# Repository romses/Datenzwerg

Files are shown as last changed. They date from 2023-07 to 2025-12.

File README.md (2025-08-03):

# Datenzwerg

## Development

Install Python 3.11. Then

1. `python -m venv venv`
2. `source venv/bin/activate`
3. `pip install -r requirements.txt`

This will install all dependencies for firmware and documentation development into a virtual environment and activate it. To leave the virtual environment, run `deactivate`.

### Firmware

The Datenzwerg firmware is based on [esphome](https://esphome.io/) which gets installed as dependency when running the above setup command.

> [!NOTE]
>
> The firmware currently requires ESPHOME 2025.7.4, as set in the `requirements.txt`. Other versions might cause errors.

To flash your own Datenzwerg, navigate to the `firmware` directory, then

1. Copy `secrets-template.yaml` to `packages/secrets.yaml` and fill in your WiFi and InfluxDB2 credentials.
2. Run `esphome -s name <gnome> run datenzwerg-{psu|battery|sensortest}.yaml` to compile and flash the firmware for your gnome named `<gnome>`.
   - `psu`: firmware optimized for deployment with a power supply; includes uptime, CO2 sensor and MQTT
   - `battery`: firmware optimized for deployment with a battery; disables uptime, CO2 sensor and MQTT but enables deepsleep
   - `sensortest`: firmware for testing all sensors; enables a webserver to check tracking

### Models

The gnome model files are based on https://www.printables.com/model/260908-garden-gnome by [Sci3D](https://www.printables.com/@Sci3D), released under CC-BY.

In the `models` directory, you will find the following files:

  - **Gnome body**
    - `datenzwerg_40p_1.2mm.blend`: Main design file, edit with [Blender](https://blender.org)
    - `datenzwerg_40p_1.2mm_top.stl`: Upper body, electronics compartment
    - `datenzwerg_40p_1.2mm_bottom.stl`: Lower body, feet, mount point
    - `datenzwerg_40p_1.2mm_bottom_poe.stl`: Lower body, feet, mount point, PoE versionA
    - `datenzwerg_logo.svg`: Logo in SVG format
  - **Gnome mounting**
    - `ground-plate-bottom.FCStd`: Ground plate design file, edit with [FreeCAD](https://freecad.org)
    - `ground-plate-bottom.stl`: Ground plate bottom part
  - **Gnome transport L-Boxx**
    - `l-boxx-136-inlay.FCStd`: L-Boxx Inlay design file, edit with [FreeCAD](https://freecad.org)
    - `label-l-boxx.svg`: Label for the L-Boxx
  - **Various labels**
    - `label-2024.svg`: Gnome label for 37c3

### Documentation

The documentation is built with [MkDocs](https://www.mkdocs.org/) which gets installed as dependency when running the above setup command. The documentation source files are located in the `docs` directory, the configuration in `mkdocs.yml` in the project root.

To run a live-reload server, run

```
mkdocs serve
```

To build the documentation, run

```
mkdocs build
```

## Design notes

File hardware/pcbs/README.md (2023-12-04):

# Gerber files

- v1.0: CCCamp2023 edition
- v1.1: 37c3 edition

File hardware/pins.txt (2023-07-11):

# Wemos D1 Mini
# -------------

TX: X           RST: D0
RX: X           A0 : X
D1: DCL         D0 : RST
D2: SDA         D5 : X
D3: X           D6 : Sensor_PWR (UV_PWR, BME_PWR, SND_PWR)
D4: X           D7 : X
G               D8 : X
5V              3V3

# ADS1115
# -------

VDD: 5V (WEMOS_5V, PWR_5V)
GND
SCL: WEMOS_D1
SDA: WEMOS_D2
X
X
A0 : UV_Out
A1 : Batt_Out
A2 : SND_Out
A3 : X

# UV
# ---

SIG: ADS1115_A0
GND
3V3: Wemos_D6

# BME280
# ------

SDA: WEMOS_D1
SCL: WEMOS_D2
GND
3V3: Wemos_D6

# SND
# ---

SIG: ADS1115_A2
GND
3V3: Wemos_D6

# PWR
# ---

SIG: ADS1115_A1
GND
5V : WEMOS_5V, ADS1115_VDD

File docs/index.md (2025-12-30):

---
description: "The Datenzwerg is a garden gnome with a mission: To collect environmental data and make it publicly available."
---

# The Datenzwerg

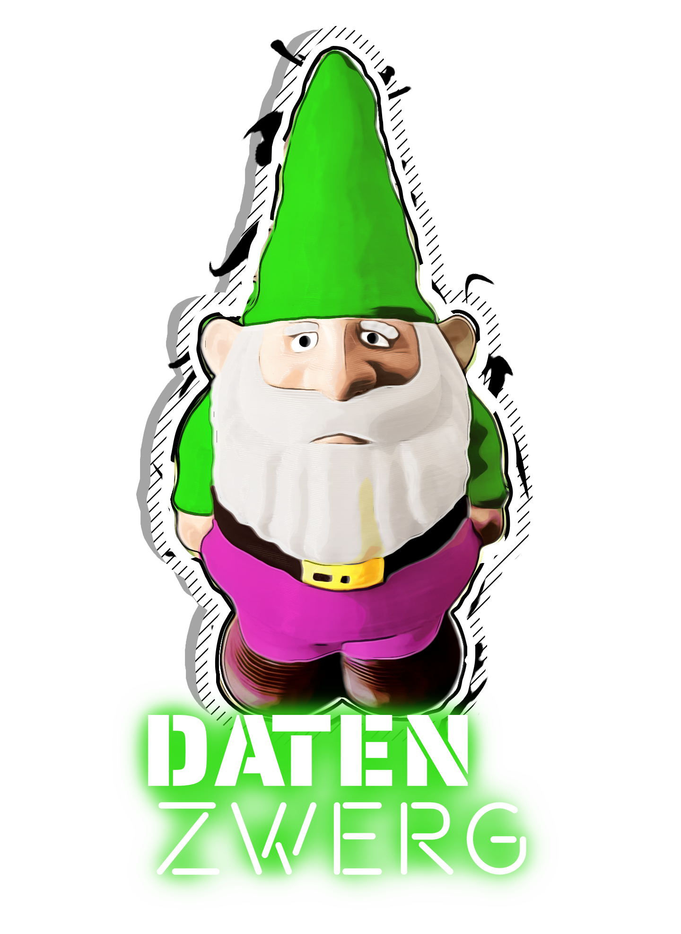
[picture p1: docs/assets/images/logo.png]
Datenzwerg logo


**Next planned deployment**: tbd

<!--
!!! tip "Datenzwerg @ 39C3"

    You are at 39C3 and came across one of the Datenzwerge? Awesome! Here's some quick links for you:

    - [What is the Datenzwerg?](#what-is-the-datenzwerg)
    - [FAQ](#faq)
    - [Fancy dashboards at grafana.datagnome.de](https://grafana.datagnome.de)

    And if you are wondering where each Datenzwerg is located, here's a quick overview. Clicking on the name will take you to the respective dashboard:

    | Datenzwerg | Location |
    | ---------- | -------- |
    | [Bashful](https://grafana.datagnome.de/d/f17a6449-84ed-4733-b982-21c0d480c42a/overview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) | Chaosmentoren |
    | [Dopey](https://grafana.datagnome.de/d/f17a6449-84ed-4733-b982-21c0d480c42a/overview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) | Food Hacking Area |
    | [Grumpy](https://grafana.datagnome.de/d/f17a6449-84ed-4733-b982-21c0d480c42a/overview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) | Memleak Bar |
    | [Happy](https://grafana.datagnome.de/d/f17a6449-84ed-4733-b982-21c0d480c42a/overview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) | C3cat Assembly |
    | [Hefty](https://grafana.datagnome.de/d/f17a6449-84ed-4733-b982-21c0d480c42a/overview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) | Chaos West |
    | [Kinky](https://grafana.datagnome.de/d/f17a6449-84ed-4733-b982-21c0d480c42a/overview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) | House of Tea |
    | [Moopsy](https://grafana.datagnome.de/d/f17a6449-84ed-4733-b982-21c0d480c42a/overview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) | Chaospost |
    | [Nerdy](https://grafana.datagnome.de/d/f17a6449-84ed-4733-b982-21c0d480c42a/overview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)  | Kidspace |
    | [Sleepy](https://grafana.datagnome.de/d/f17a6449-84ed-4733-b982-21c0d480c42a/overview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) | Saal 4 Chillout |
    | [Sneezy](https://grafana.datagnome.de/d/f17a6449-84ed-4733-b982-21c0d480c42a/overview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) | Hardware Hacking |
-->

## What is the Datenzwerg?

The Datenzwerg is a garden gnome with a mission: To collect environmental data and make it publicly available. 

It was originally developed for the [Chaos Communication Camp 2023](https://events.ccc.de/camp/2023/infos/) where we ([@romses](https://chaos.social/@romses) and [@foosel](https://chaos.social/@foosel)) deployed a small army of 10 Datenzwerge across the camp grounds: Happy, Doc, Grumpy, Dopey, Bashful, Sleepy, Sneezy, Nerdy, Kinky and Hefty[^1]. Since then, Doc has gotten a new home at the CERT and the official Datenzwerg family now consists of Bashful, Dopey, Grumpy, Happy, Hefty, Kinky, Moopsy, Nerdy, Sleepy and Sneezy.

The Datenzwerge also made a reappearance at the [37c3](https://events.ccc.de/congress/2023/infos/index.html), the [GPN22](https://entropia.de/GPN22), the [MRMCD 2024](https://2024.mrmcd.net/de/) and [38c3](https://events.ccc.de/congress/2024/infos/index.html). They are scheduled to make an appearance at [WHY2025](https://why2025.org/).

The Datenzwerg consists of a 3D printed gnome body, a custom PCB with an ESP8266 D1 Mini microcontroller board, a BME280, SCD41, UV and sound sensor and an optional 18650 battery. It's powered by [ESPHome](https://esphome.io/) and sends its data to an [InfluxDB](https://www.influxdata.com/) instance. The firmware currently logs temperature, relative and absolute humidity, air pressure, dew point, UV index, CO2 and sound pressure.

## A short history of the Datenzwerg

2023-06-11
: The idea of the Datenzwerg is born at the final day of  [GPN21](https://entropia.de/GPN21), just before a joint bar shift by [@romses](https://chaos.social/@romses) and [@foosel](https://chaos.social/@foosel). 
  Slow parts of the shift as well as the drive back to the Rhein-Main-Area are spent discussing the idea. Romses registers a domain name.

2023-06-30
: romses and foosel meet up for a joint tinkering session. The first two mainboards are built. The Datenzwerg is alive!

2023-07-08
: Another joint tinkering session takes place. Another 8 mainboards are built. The Datenzwerg army is growing!

2023-07-19
: After finalizing the model and followed by 60+ hours of collective print time, all 10 Datenzwerg bodies are printed.

2023-07-23
: The basic infrastructure goes live. Sensors start to report to the official servers at [datagnome.de](https://datagnome.de).

: All Datenzwerg bodies are prepared for getting their electronics installed: Magnets are glued in, the UV transmissive discs are installed and any holes filled with milliput.

2023-07-24
: The firmware reaches a first feature complete state.

2023-07-28
: All Datenzwerge are now in their bodies and are happily sending data.

2023-08-04
: The website reaches a first complete state in both German and English.

2023-08-09
: The sensor data is publicly available via InfluxDB and MQTT.

: The firmware sees final adjustments in preparation for the Camp.

2023-08-11
: The Datenzwerge are offline again, temporarily. Next stop: CCCamp!

2023-08-15 - 2023-08-19
: Datenzwerg deployment at [CCCamp23](https://events.ccc.de/camp/2023/infos/).

2023-08-19
: (Almost) all Datenzwerge have left the camp and are traveling back to the Rhein-Main-Area. Thanks everyone for the big interest!

2023-08-22
: The Datenzwerge are back home and are being prepared for future deployments. The CCCamp data export is [available in the repository](https://github.com/romses/Datenzwerg/tree/main/camp23_data).

2023-08-28
: The infrastructure has been shut down for now and only the page here and of course the source code remains. The Datenzwerge are taking a well deserved rest.

2023-10-31
: Work has started on the 37c3 edition of the Datenzwerg. The plan is to add TVOC monitoring to the sensor suite. A new PCB has been designed, ordered, arrived, and ten new mainboards have been soldered.

2023-12-08
: An alternative version of the bottom part of the Datenzwerg is finished that allows leading through a cable. Ten new bottoms have been printed and magnetised to allow for USB or POE powering at 37c3. This completes the hardware side of the 37c3 preparations.

2023-12-11
: The server infrastructure is back up an running and the first Datenzwerge are reporting data again.

2023-12-26 - 2023-12-30
: The Datenzwerge are deployed at 37c3.

2024-05-30 - 2024-06-02
: Five Datenzwerge are deployed at GPN22.

2024-10-03 - 2024-10-06
: Eight Datenzwerge are deployed at MRMCD2024.

2024-12-27 - 2024-12-30
: The Datenzwerge are deployed at 38c3.

2025-08-08 - 2025-08-11
: The Datenzwerge are deployed at WHY2025.

## FAQ

### What kind of data does the Datenzwerg collect?

The Datenzwerg contains sensors to collect the following data:

- Temperature
- Relative humidity
- Air pressure
- CO2
- UV sensor voltage
- Microphone voltage
- Battery voltage
- WiFi signal strength

We calculate dew point and absolute humidity from the temperature and relative humidity values, UV index from the UV sensor's voltage and sound pressure (noise level) from the microphone voltage. The calculations are done in firmware.

### Do you record audio?

No. While there is a microphone inside each Datenzwerg hooked up to the ESP's ADC, we only use it to sample 1s of audio every 5s, from which we calculate the peak-to-peak voltage and from that the sound pressure on the Datenzwerg itself. The sample rate is way too low and irregular to record any meaningful audio, and the noise on the line vs the 10-bit ADC would make for a bad experience as well if that was our intention. We are not interested in audio, we are interested in noise levels.

### What's the battery life?

In our tests, a Datenzwerg without CO2 sensor seems to last between three to four days on a single charge of our 18650 LiPos that range from 1600mAh to 2800 mAh. This obviously depends on the cell capacity but also temperature and other environmental factors.

With the CO2 sensor included powering via a single 18650 LiPo is sadly not working out.

### Why are the measured temperatures that high during the day?

We need to put the gnomes into direct sunlight in order to be able to measure UV index. Additionally, the ESP and now also the TVOC sensor are producing heat themselves. We tried to get enough airflow inside the gnome body, but sadly the material itself radiates off heat a lot. As such, the temperature readings are distorted, especially under direct sun light.

### Where can I find the data?

Each Datenzwerg sends its data to a central self-hosted InfluxDB instance. The data is then visualized using Grafana. 

Some of those visualisations as well as credentials for accessing the raw data and links to data exports from past events can be found [here](./sensors/).

### Where can I find the source?

Everything can be found in this GitHub repository: [romses/Datenzwerg](https://github.com/romses/Datenzwerg).

## Media echo

- The datagnomes were the opener at the #cccamp23 review [media.ccc.de](https://media.ccc.de/v/camp2023-57105-cccamp23_review).
- romses and foosel were guests at the [Datenleben Podcast](https://www.datenleben.de/index.php/2023/10/14/dl043-perspektiven-auf-data-science/) and talked about the Datenzwerge (German).
- The Datenzwerg project was also a topic on [C-RadaR](https://www.c-radar.de/2024/06/c-radar-juni-2024-datenzwerge-clubsareculture-verstehbahnhof-emf-camp/)

## Credits & Thanks

The Datenzwerg was created by [@romses](https://chaos.social/@romses) and [@foosel](https://chaos.social/@foosel).

The Datenzwerg logo was created by D.B.

The Datenzwerg model files are based on [this "Garden Gnome" model](https://www.printables.com/model/260908-garden-gnome) by [Sci3D](https://www.printables.com/@Sci3D), released under CC-BY. Our remix can be found [here](https://www.printables.com/model/534875-datenzwerg-enclosure) and of course also [in the GitHub repository](https://github.com/romses/Datenzwerg/tree/main/models).

The SCD41 sensors were sponsored by [@dx@mastodon.social](https://chaos.social/@dx@mastodon.social).

[^1]: Yes, the last three are not canon, and one of them even is a smurf - so what, chaos ftw!

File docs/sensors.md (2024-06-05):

---
description: "A look at the current Datenzwerg sensor data."
---

# Current Datenzwerg data

<!--
There is currently no current Datenzwerg data. Check again when they are back at an event.
-->

## Environmental data

{% for env in grafana.environment %}
=== "{{ env.name }}"
    <iframe src="{{ grafana.base_url }}{{ env.panel }}" class="grafana-iframe"></iframe>
{% endfor %}

## Internal data

{% for env in grafana.internal %}
=== "{{ env.name }}"
    <iframe src="{{ grafana.base_url }}{{ env.panel }}" class="grafana-iframe"></iframe>
{% endfor %}

The full set of grafana dashboards are available at <a href="https://grafana.datagnome.de">grafana.datagnome.de</a>

## Raw data

If you are interested in the raw data, connect to our InfluxDB or MQTT (read-only):

  - InfluxDB:
    - Host: `influxdb.datagnome.de`
    - Port: 8086
    - Organization: `datagnome`
    - Bucket: `datagnome`
    - Auth token: `5amv72PFZxPmnbUISjntEVxtElDYMhkeofg9Deo1ykO6Zy2XIba_iWPcyxyAp_R0dHsvHm5moE4YBCwxGIEriw==`
  - MQTT:
    - Host: `mqtt.datagnome.de`
    - Port: 1883
    - User: `readonly`
    - Password: `readonly`

## Exports of past events

You can find the data export of CCCamp23 [on the repo](https://github.com/romses/Datenzwerg/tree/main/exports/cccamp2023).

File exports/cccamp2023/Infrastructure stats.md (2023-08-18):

Batteriewechsel:
  - Bashful: 2
  - Doc: 2
  - Dopey: 1
  - Grumpy: 1
  - Happy: 1
  - Hefty: 2
  - Kinky: 2
  - Nerdy: 1
  - Sleepy: 1
  - Sneezy: 1
  ---------------
  - total: 14

Stromverbrauch:
  - Bashful: 3 Ah
  - Doc: 3Ah
  - Dopey: 1,5Ah
  - Grumpy: 1,5Ah
  - Happy: 1,5Ah
  - Hefty: 3Ah
  - Kinky: 3Ah
  - Nerdy: 1,5Ah
  - Sleepy: 1,5Ah
  - Sneezy: 1,5Ah
  ----------------
  - total: 21Ah		-> 77 Wattstunden
  
Signal losses:
  - Bashful: 13
  - Doc: 
  - Dopey: 6
  - Grumpy: 5
  - Happy: 
  - Hefty: 3
  - Kinky: 8
  - Nerdy: 3
  - Sleepy: 2
  - Sneezy: 7
  ---------------
  - Most realiable dwarf: Doc/Happy (0)
  - Most lazy dwarf: Bashful (13)
  
Top values:
  - Temperature Max: 44°C (Hefty 2023-08-16 13:40)
  - Temperature Min: 12,8°C (Doc 2023-08-14 6:20)

  - Pressure Max: 1019 mbar
  - Pressure Min: 998 mbar
  
  - Humid Max: 100% (Sleepy 2023-08-16 3:40)
  - Humid Min: 23,9% (Dopey 2023-08-16 16:20)
  
  - UV Max: 9 (Doc 2023-08-16 13:20)

  - SND Max: 94dB (Kinky 2023-08-16 8:00)
  
  - Wifi Max: -69dB (Happy)
  - Wifi Min: -82dB (Sleepy)

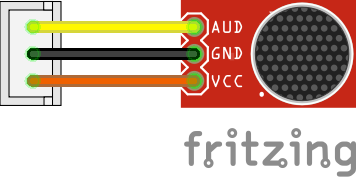
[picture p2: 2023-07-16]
docs/assets/images/Sound-module-fritzing.png

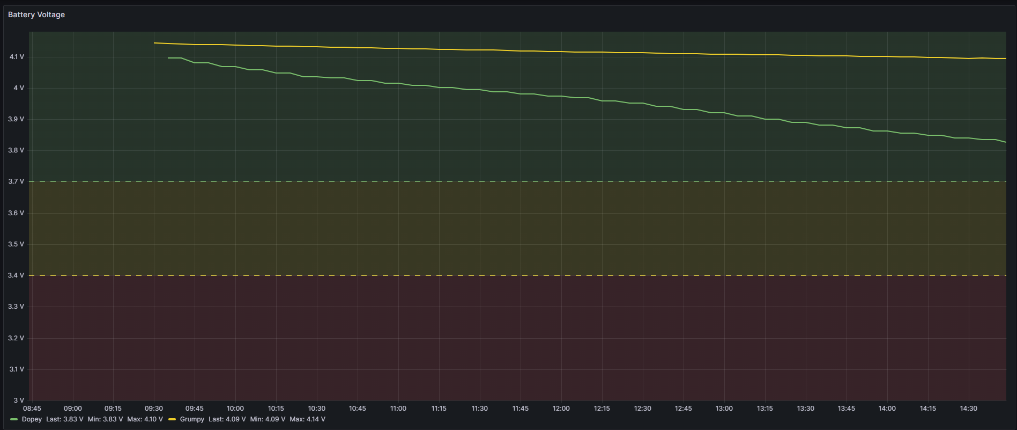
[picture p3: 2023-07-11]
images/Deep-Sleep.png

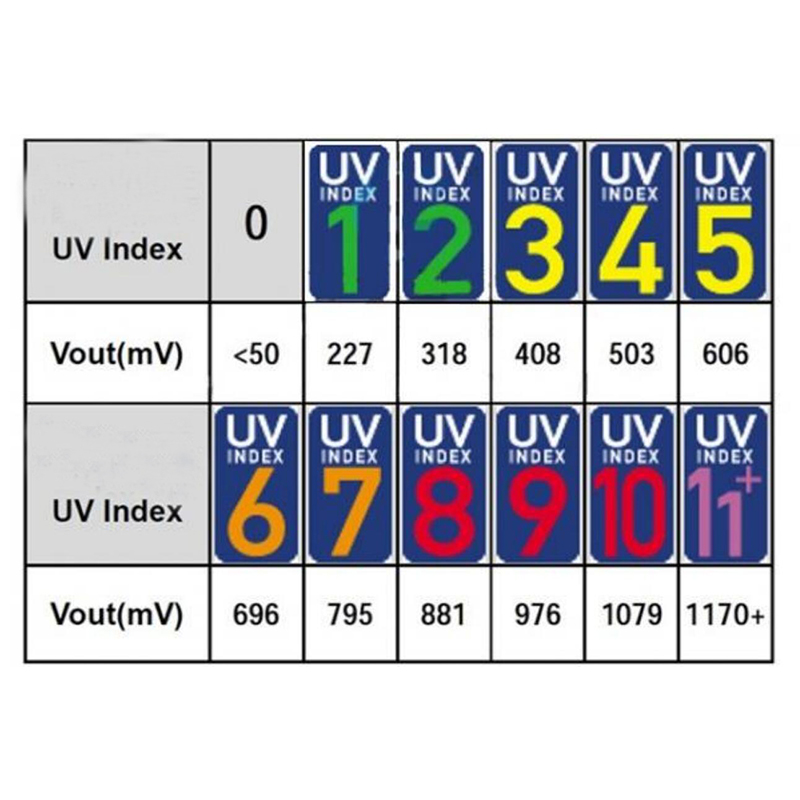
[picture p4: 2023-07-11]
images/UV-Index-table.jpg

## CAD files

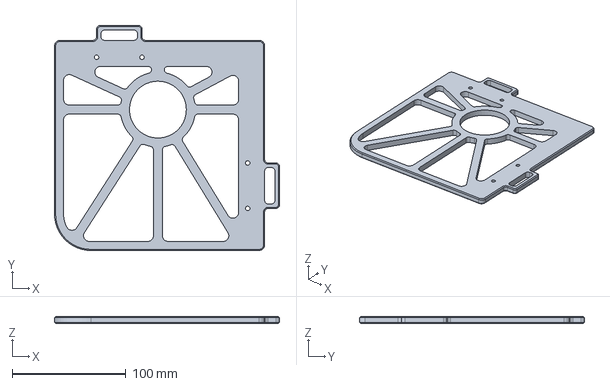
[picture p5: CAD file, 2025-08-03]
models/ground-plate-bottom.FCStd
198.0 x 198.0 x 6.00 mm

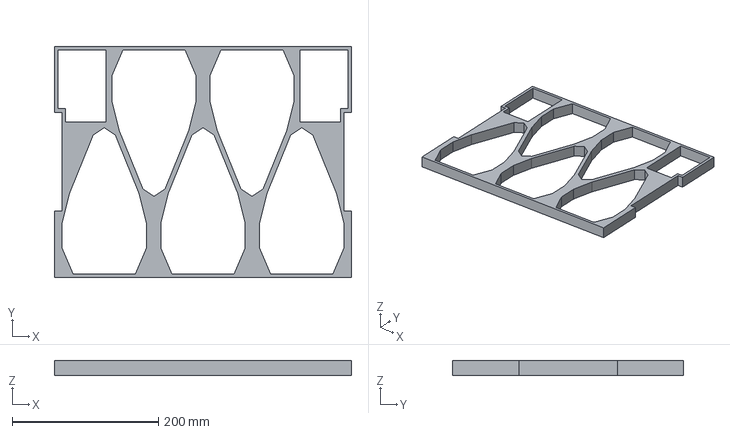
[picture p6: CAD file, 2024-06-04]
models/l-boxx-136-inlay.FCStd
406.0 x 316.0 x 20.0 mm

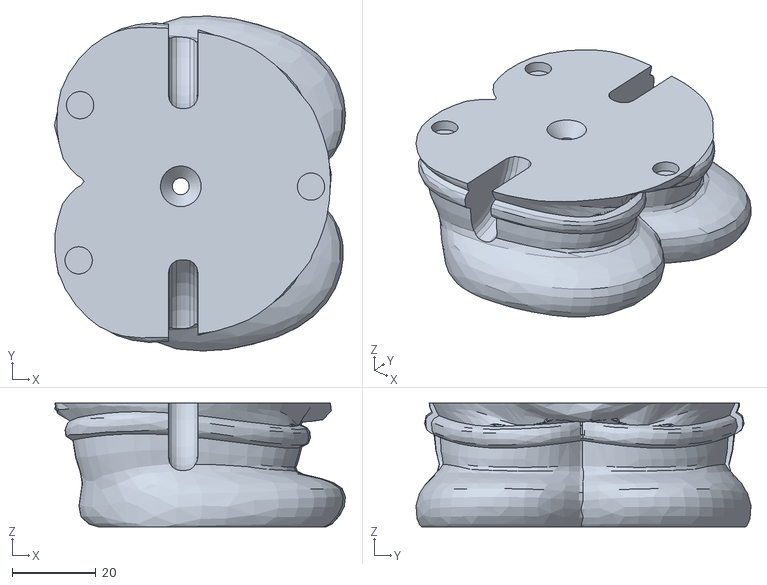
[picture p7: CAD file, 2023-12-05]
models/datenzwerg_40p_1.2mm_bottom_poe.stl
69.3 x 79.8 x 29.4

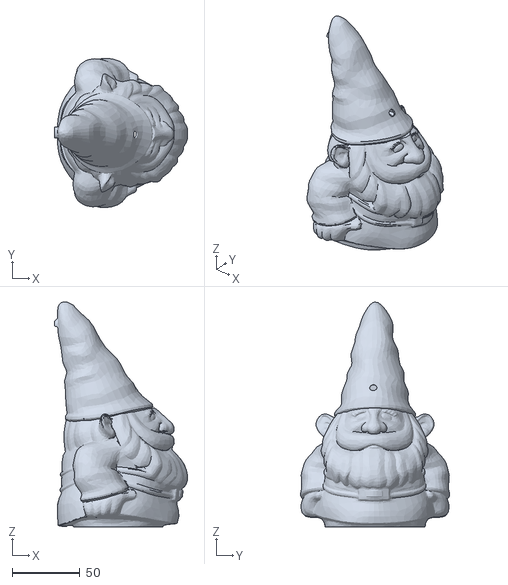
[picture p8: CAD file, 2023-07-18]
models/datenzwerg_40p_1.2mm_top.stl
98.4 x 110.3 x 166.2

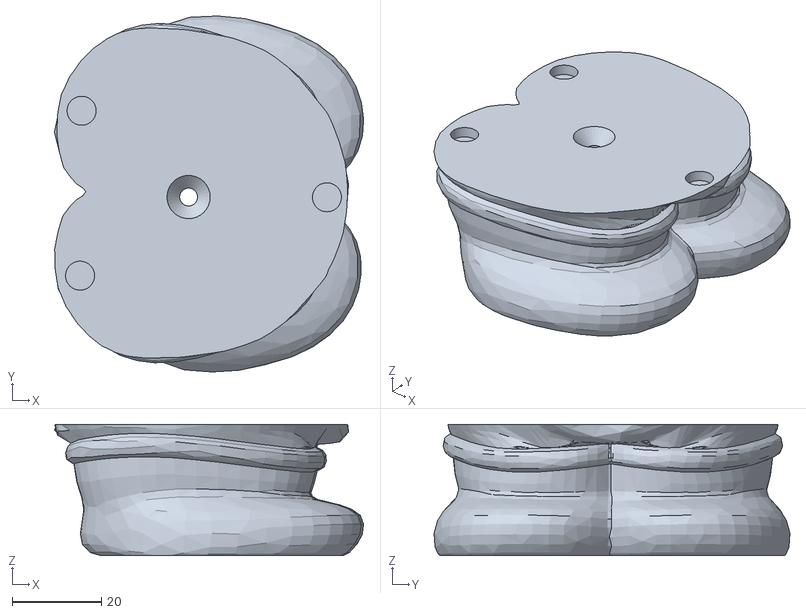
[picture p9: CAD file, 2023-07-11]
models/datenzwerg_40p_1.2mm_bottom.stl
69.3 x 79.8 x 29.4

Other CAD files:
models/ground-plate-bottom.stl

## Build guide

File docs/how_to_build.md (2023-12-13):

---
description: You want to build your own Datenzwerg? Here's a build guide!
---

# How to build a Datenzwerg

!!! warning
    
    The Datenzwerg was initially developed for the [CCCamp23](https://events.ccc.de/camp/2023/infos/) and later adapted for [37c3](https://events.ccc.de/congress/2023/infos/index.html). Hardware, firmware and models were chosen and designed for a specific purpose and a specific deployment duration and might not be suitable for other use cases. The Datenzwerg is provided as-is without any warranty, and also for now without any plans to improve or fix it or any other support. If you want to build your own Datenzwerg, you are mostly on your own.

## Prerequisites

Building a Datenzwerg requires some soldering and 3D printing skills.

The firmware provided with the Datenzwerg requires you to provide it with credentials for an existing WiFi network (SSID and password) and also access to an [InfluxDB2](https://influxdb.com) instance (host, port, organization id, bucket name and write-enabled access token). You will need to provide these credentials in a file called `secrets.yaml` in the `firmware` directory. A template for this file is provided in `firmware/secrets-template.yaml`.

## Parts

### Electronics

To build your own Datenzwerg, you will need the following parts:

| Count | Item | Function | Link |
| ----- | ---- | --- | ---- |
| 1 | Wemos D1 Mini | MCU | [AliExpress](https://aliexpress.com/item/1005004967205772.html) |
| 1 | BME280 | Environment Sensor | [AliExpress](https://aliexpress.com/item/1005003676342598.html) |
| 1 | SGP30 | TVOC/eCO2 Sensor | [AliExpress](https://aliexpress.com/item/1005004680000599.html) |
| 1 | VEML6075 | UV Sensor | [AliExpress](https://aliexpress.com/item/1005004653958045.html) |
| 1 | ADS1115 | 4 Port ADC | [AliExpress](https://aliexpress.com/item/32817162654.html) |
| 1 | GY-MAX4466 | Sound sensor | [Amazon](https://www.amazon.de/dp/B07YDG3VZF) |
| 3 | male 3-pin JST connectors + cables | Sensor & power connectors | [Amazon](https://www.amazon.de/gp/product/B08ZJ6JGB5) |
| 2 | male 4-pin JST connectors + cables | I2C connector | [Amazon](https://www.amazon.de/gp/product/B09LCRCTQG) |
| 2 | male 8-pin headers, male and female | ESP8266 connector | [Amazon](https://www.amazon.de/dp/B07DBY753C/) |
| 1 | male 10-pin header, male and female | ADS1115 connector | [Amazon](https://www.amazon.de/dp/B07DBY753C/) |

Additionally you'll need a soldering iron, solder, some wires and shrink tubing.

!!! warning

    We use BM**E** sensors. They are often mixed up with the BM**P** sensors, which lack the humidity sensor.
    You can identify your module with the help of a picture on this (german) [page](https://homematic-forum.de/forum/viewtopic.php?t=68558).

!!! warning

    If you want to battery power your Datenzwerg, do not use the SGP30 sensor. It requires constant power to work properly and will not work with deep sleep. Leave it unpopulated and adjust the firmware config as described below.

!!! note

    We recommend using all parts from the BOM. However, if you want to save money, you can directly solder the sensors to the board and save a little bit on the 
    connectors. You can also save a little bit by skipping the TP4056 and soldering the wires directly to the LiPo. Be warned though that this module provides 
    undervoltage protection to the LiPos.

### Gnome body

If you want to put the Datenzwerg into its gnome body, you will also need:

| Count | Item | Function | Link |
| ----- | ---- | --- | ---- |
| 1 | 3D printed gnome body top | Gnome body | [Download](https://raw.githubusercontent.com/romses/Datenzwerg/main/models/datenzwerg_40p_1.2mm_top.stl) |
| 1 | 3D printed gnome body bottom | Gnome body | [Download (closed)](https://raw.githubusercontent.com/romses/Datenzwerg/main/models/datenzwerg_40p_1.2mm_bottom.stl) or [Download (cable throughholes)](https://raw.githubusercontent.com/romses/Datenzwerg/main/models/datenzwerg_40p_1.2mm_bottom_poe.stl) |
| 6 | 6x1mm neodymium disc magnets | Connecting the top and bottom of the gnome body | [Amazon](https://www.amazon.de/dp/B007JTKX3Y) |
| 1 | ~3mm thick sanded and polished cut-off of a 5mm rod of 0A070GT Plexiglas XT | UV transmissive rain cover for the UV sensor | [Sample from the manufacturer](https://www.plexiglas-shop.com/en-de/products/plexiglas-xt/sr0a070gt.html) |

For assembly you'll also need hotglue, superglue and UV resin.

!!! note

    It is strongly recommended to print the gnome body with a 0.6mm nozzle and 0.4mm layer height. The model is designed for this combination and might not work with other nozzle sizes or layer heights.

    With such a setup, print both parts with 3 walls, 3 bottom/top layers, 20% infill and tree supports. The top part should take around 5h to print, the bottom part around 1h.

!!! hint

    We got a 100mm sample rod of the Plexiglas XT from the manufacturer for 3€. We cut it to length with a Dremel and [this 3d printed cutting jig](https://www.printables.com/model/113887-rod-and-tube-cutter-for-dremel-with-limiter), then sanded the cut-off smooth with 240 and 400 grit and polished it with a general polishing compound ("Elsterglanz")[^2].

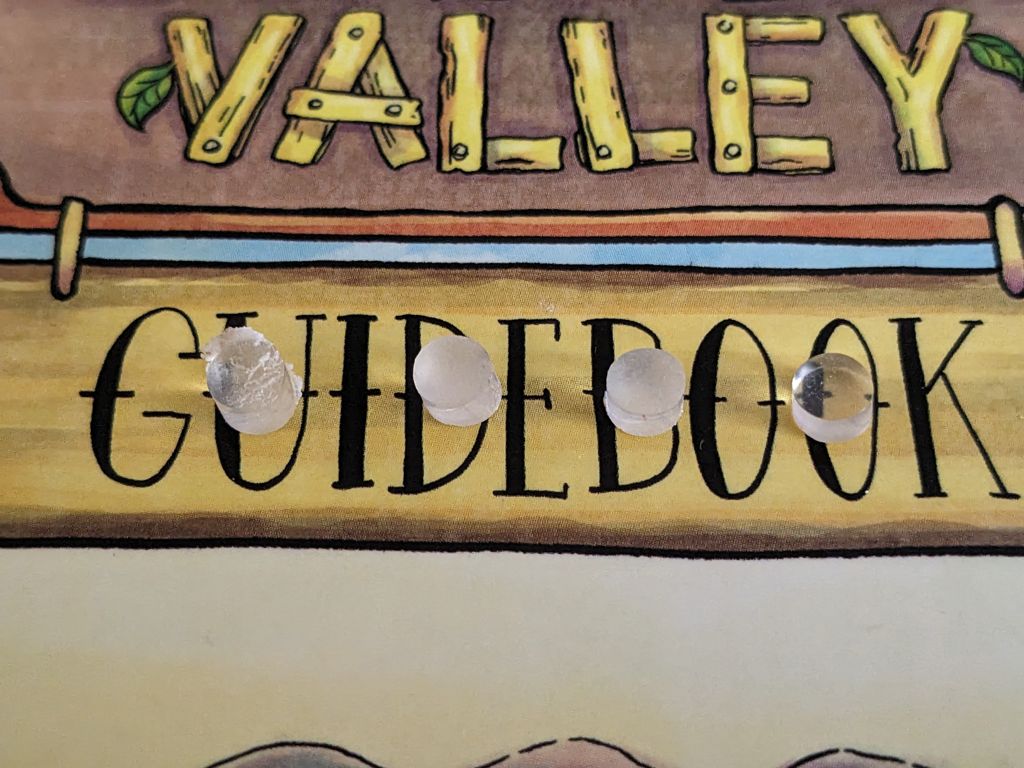
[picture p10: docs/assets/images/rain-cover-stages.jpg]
The four stages of a rain cover: Cut-off from the rod, sanded with 240 grit, sanded with 400 grit, polished.
    

### Battery power module

If you want to have the Datenzwerg running on battery power, you will also need:

| Count | Item | Function | Link |
| ----- | ---- | --- | ---- |
| 1 | TP4056 | Lipo Charger | [AliExpress](https://aliexpress.com/item/32624444293.html) |
| 1 | 5V MT3608 boost converter | Power supply | [AliExpress](https://de.aliexpress.com/item/4001066566291.html) |
| 1 | 18650 LiPo battery | Power source | (on hand)[^1] |
| 1 | 18650 LiPo battery holder | Battery holder | [Amazon](https://www.amazon.de/dp/B08Y5R63YB) |
| 1 | male 2-pin JST cable male + JST cable female | Battery cable | [Amazon](https://www.amazon.de/GTIWUNG-Steckverbinder-Pin-Verbindungsstecker-Connector-Kabeldraht/dp/B07VYR7J49) |

### MicroUSB power module

If you want to have the Datenzwerg running on MicroUSB power, you will also need:

| Count | Item | Function | Link |
| ----- | ---- | --- | ---- |
| 1 | Micro USB breakout board | Power connector | [Amazon](https://www.amazon.de/gp/product/B0BZDL6GKC/) |

In that case you should also chose the gnome body bottom with the cable throughholes.

## Assembly

### Mainboard

=== "PCB"

    We designed a PCB for the Datenzwerg and got it manufactured. You can find the Gerber files [here](https://github.com/romses/Datenzwerg/tree/main/hardware/pcbs/v1.1).

    Assembling the Datenzwerg mainboard with such a PCB is quite straightforward. Populate the
    ENV and TVOC spots with the 4-pin JST headers and the UV, SND and Power spots with the 
    3-pin JST headers. Then solder two 8-pin headers to the ESP8266 spots and one 10-pin header
    to the ADS1115 spot. 

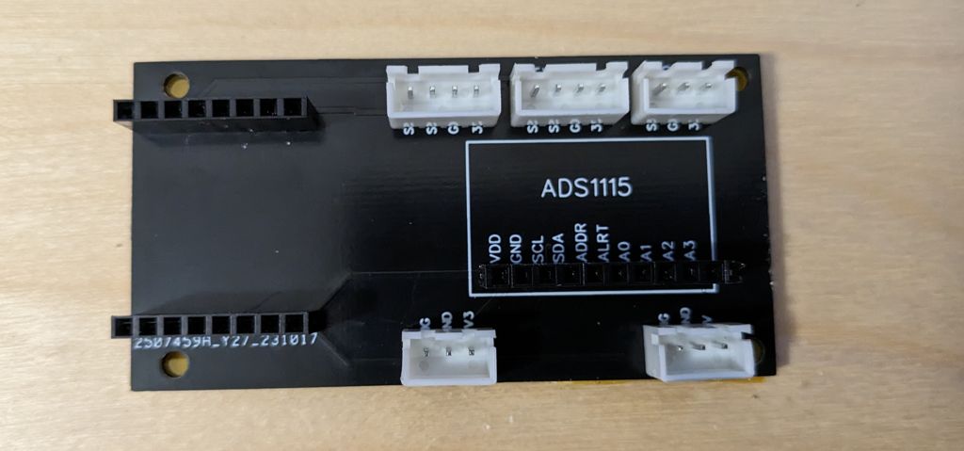
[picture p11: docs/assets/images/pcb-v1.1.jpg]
The Datenzwerg mainboard PCB in version 1.1
    

    Then sadly some manual rework is needed: Use a piece of jumper wire and on the underside of the PCB bridge the 3v3 pin of the ESP8266 to the 3v3 pin of either the TVOC or ENV sensor.

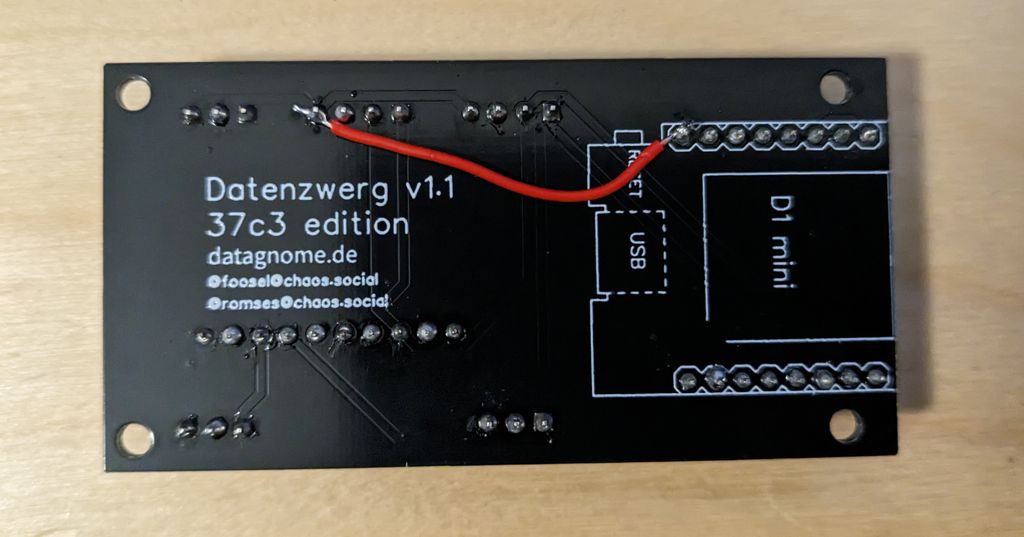
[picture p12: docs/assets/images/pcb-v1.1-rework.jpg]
The Datenzwerg mainboard PCB in version 1.1 with the applied rework
    

=== "Hand soldering on perfboard (v1.0 only)"

    The mainboard is the hardest part to assemble. We recommend to first wire up the 3V3 power trail (orange in the Fritzing drawing) and the GND connections (black), then the I2C trail (green and yellow).
    Those are the most complex traces. Next do the 5V connections (red) and finally the analogue signals (cyan).
    
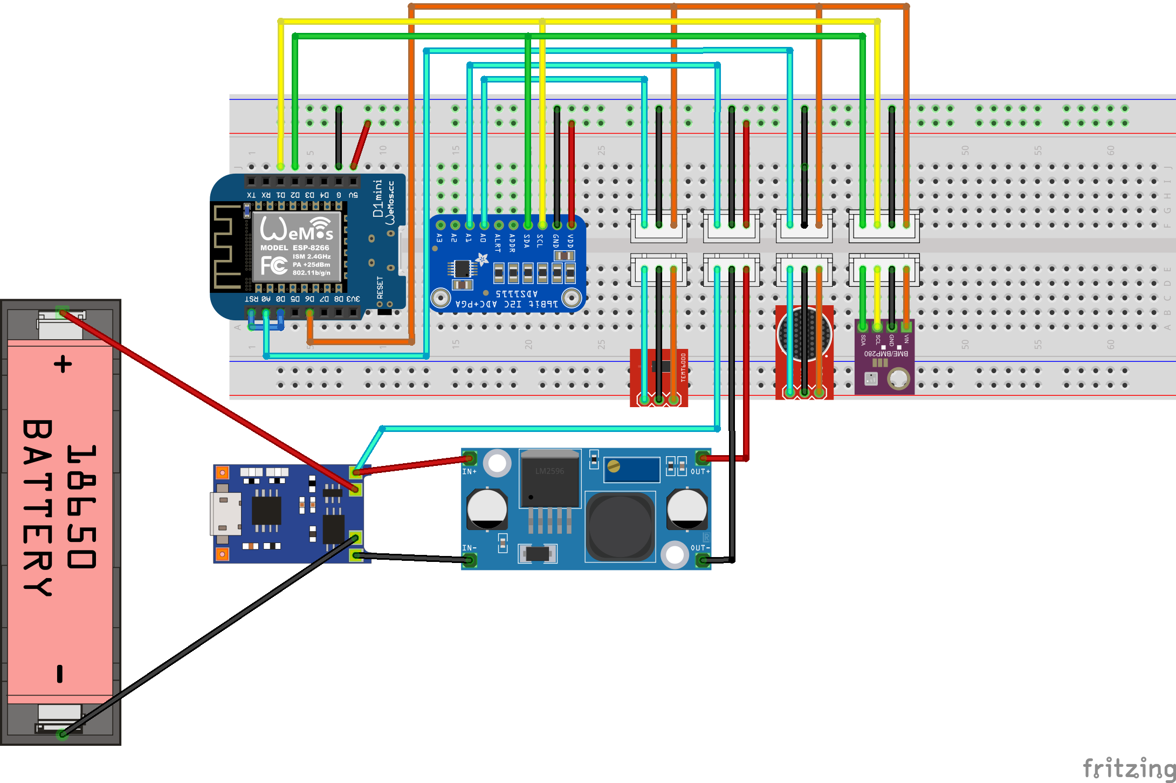
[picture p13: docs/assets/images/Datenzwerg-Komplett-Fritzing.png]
The Datenzwerg mainboard as a Fritzing schematic
    
    
    The Fritzing schematic shows the ESP in its original orientation. However, we decided to mount the ESP flipped over. The diagram also shows the ADS1115 in a rotated orientation. This makes the fritzing 
    diagram much easier to understand.
    
    The Datenzwerg mainboard as a PCB schematic
    
    The PCB schematic shows the ESP in the correct orientation as well as the ADS1115. This schematic is much closer to our hand soldered boards than shown in the Fritzing diagram.
    
    The Datenzwerg mainboard, assembled on perfboard
    
    !!! note
        
        We used a special kind of perfboard. The grouping of three pin holes makes organising the wires so much easier.
        
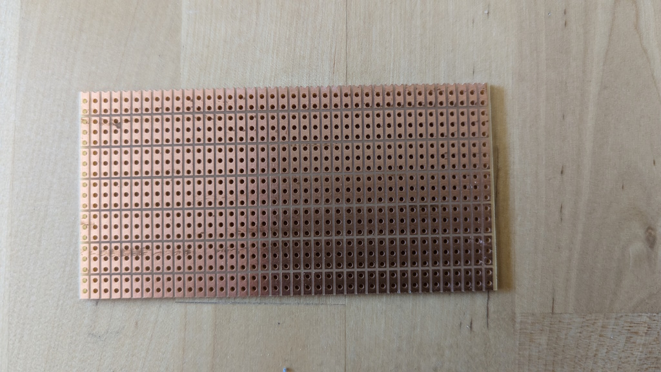
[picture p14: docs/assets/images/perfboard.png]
Perfboard sample
        
    
        You can find this perfboard on [Amazon](https://www.amazon.de/gp/product/B085WJCRX8/).

Once you are done soldering up the mainboard, we recommend covering the underside in wide strips of Kapton tape to prevent shorts. Alternatively you may use electric tape.

!!! note

    Things to check after soldering:

    - UV sensor, BME280, SGP30 and sound sensor are powered by 3V3 coming from the ESP.
    - ADS1115 and ESP are powered by 5V coming from the power supply module.
    - All GNDs are connected.
    - No shorts between any of the pins, especially between neighbouring pins bridges can quickly happen. Use a multimeter to check for shorts.

### Sensors

#### UV and sound sensor

The UV and sound sensors are soldered to JST connector cables to make the sensors replaceable. They share their wiring. Make sure to (carefully!) rotate the potentiometer on the back of the sound sensor to the left-most (clockwise) position, that will set the correct gain of 25x that matches the firmware. Apply shrink tube to protect the soldering joints and reduce the likelihood of shorts.

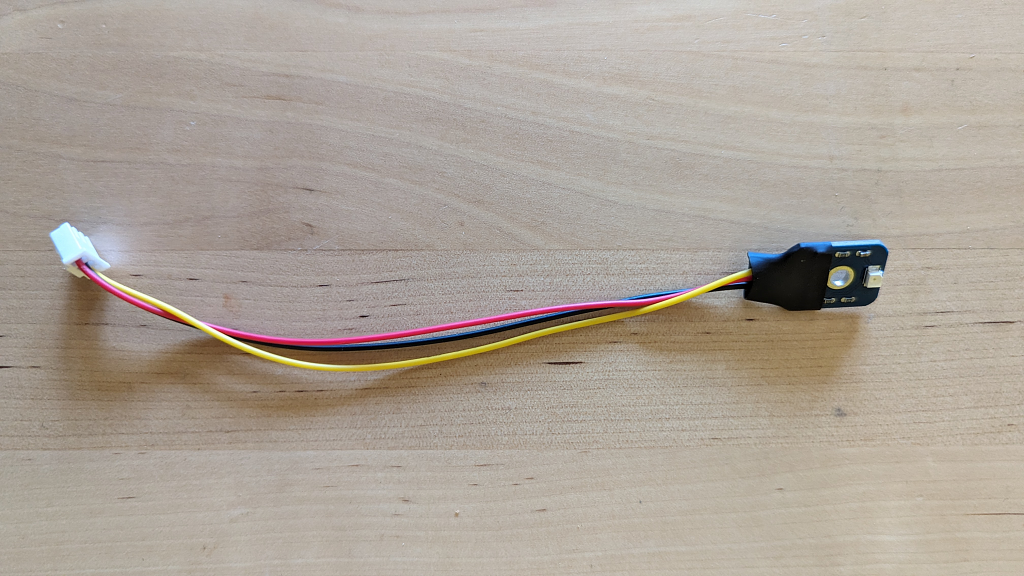
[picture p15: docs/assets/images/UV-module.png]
The UV module

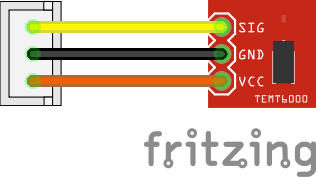
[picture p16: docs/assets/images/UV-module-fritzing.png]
The UV module as a Fritzing schematic, showing how to connect the JST header. Orange to Vcc, Black to GND, Yellow to Signal


#### BME280 und SGP30 sensor

The BME280 and SGP30 sensors are soldered to a 4-pin JST header. Apply shrink tube to protect the soldering joints and reduce the likelihood of shorts. 

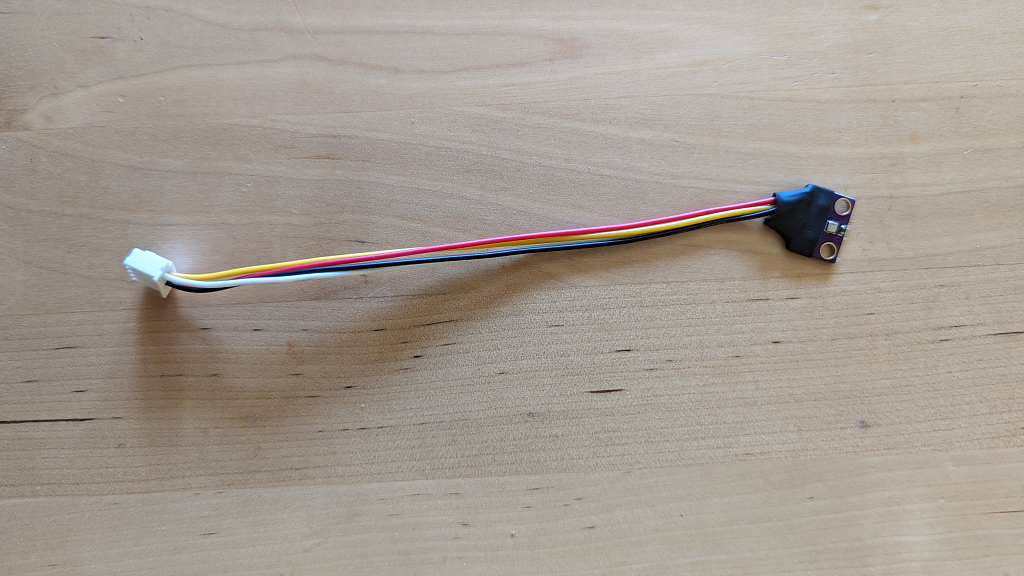
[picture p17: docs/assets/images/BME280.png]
The BME module

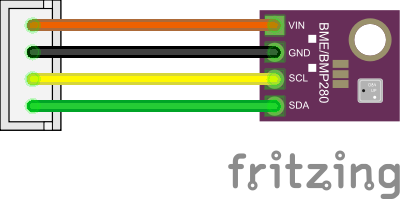
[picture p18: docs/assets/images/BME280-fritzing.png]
The BME module as a Fritzing schematic, showing how to connect the JST header. Orange to Vin, Black to GND, Yellow to SCL, Green to SDA


!!! note
    
    The temperature inside the Datenzwerg can become much warmer than the outside temperature. We found that even sticking the BME280 outside of the Datenzwerg, by pushing it through the slot on the bottom of the top of the Datenzwerg case, the temperature readings were still extremely high when the Datenzwerg was in direct sunlight, possibly due to radiation of the heated up plastic of the Datenzwerg body. We decided to live with this issue and just note it in the documentation. A different case design could possibly solve this issue.

### Power supply

=== "Battery power"

    The Power supply is the second complex component of the Datenzwerg.
    
    In our original design it was intended to charge the LiPos directly via the TP4056 modules. However, tests have shown that these modules become very hot during charging - we measured up to 86°C, and that was too high for us to
    feel good about charging them this way on the possibly very dry field of the CCCamp.
    
    Therefore, we charge the LiPos externally in an off-the-shelf LiPo charger. We however kept the modules to prevent deep discharge.
    
    The BAT+ and BAT- terminals are connected to VIN+ and VIN- of boost converters set to 5V output voltage. Both the ADS1115 and the ESP8266 could be operated with 3V3. However, the TP4056 module supplies battery voltage. Therefore, the easiest way was to boost the voltage to 5V using a boost converter to power both the ESP8266 and the ADS1115. This has also the added advantage of allowing us to measure the battery voltage using the ADS1115, which is able to measure voltages up to Vcc + 0.3V. We therefore connected the third wire of the 3-pin JST header used for the connection to the mainboard to VIN+, with the other two wires connected to VOUT+ and VOUT-.
    
    Shrink tube is applied to protect the soldering joints and reduce the likelihood of shorts.
    
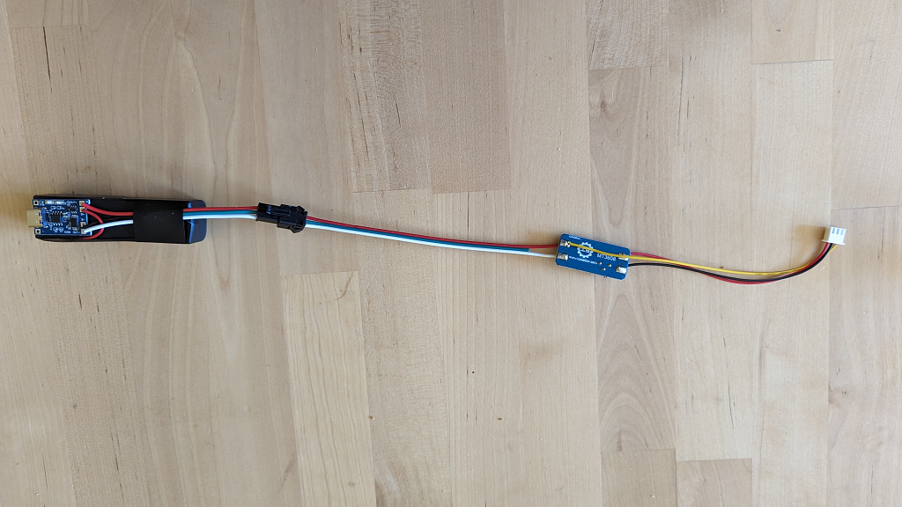
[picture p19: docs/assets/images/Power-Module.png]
The assembled power module
    
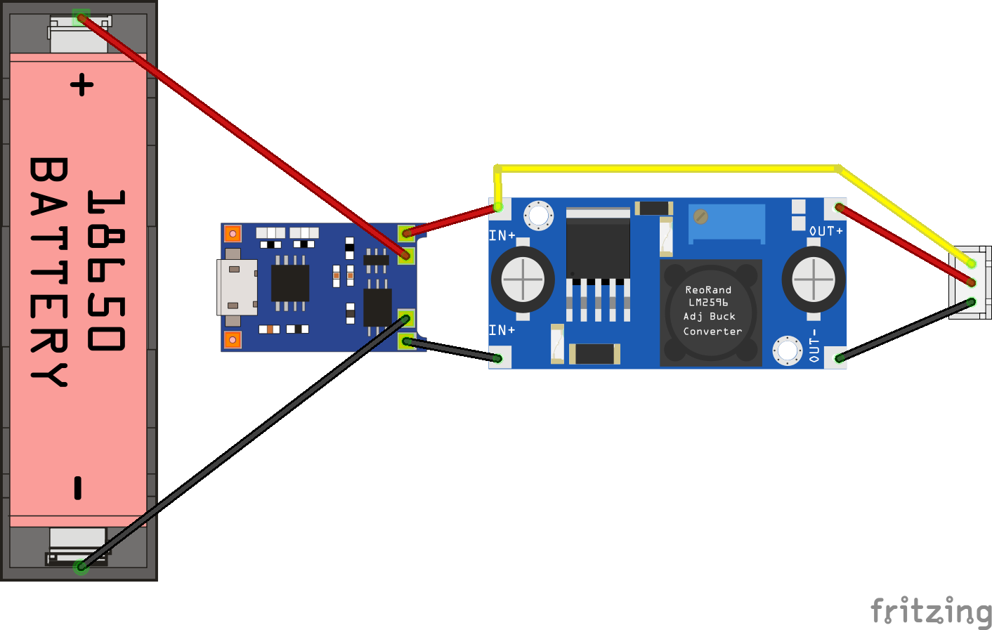
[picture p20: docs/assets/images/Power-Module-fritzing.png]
The power module as a Fritzing schematic, connections as written above
    

=== "MicroUSB power"

    The MicroUSB power module is much simpler than the battery power module. It is simply a MicroUSB breakout board soldered to a 3-pin JST header, red to 5V, black to GND, the yellow sensor cable is cut off. Shrink tube is applied to protect the soldering joints and connector and reduce the likelihood of shorts.
    
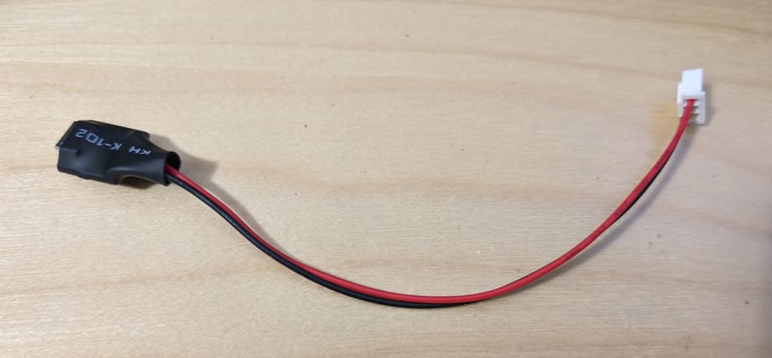
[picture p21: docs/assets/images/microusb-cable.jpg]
The assembled MicroUSB power module
    
    
### Gnome body

Using superglue, glue the magnets into the holes in the gnome body - there are three each on the mating surfaces of top and bottom part. Make sure the polarity is correct, i.e. the magnets attract each other when the gnome body top is placed on the bottom. The magnets should be flush with the surface.

Fit the acrylic rain cover into the hole in the hat. If it won't fit right away, carefully sand the print until it does. It should be flush with the inner surface of the gnome body, it's ok if it protrudes a bit on the front. Carefully - making *really* sure to not get any on the central surface of the acrylic disc - apply UV resin around the edges of the rain cover. Then cure it with a UV lamp. 

!!! warning

    Make sure to not get any UV resin on the surface of the acrylic disc. If you do, it will be permanently fogged up.

Use a small screwdriver or other tool to hold the UV sensor in place with its shrink tubing. Apply hot glue on the shrink tubing and then press the sensor into its final position so that the sensor is centered inside the acrylic window.

Apply hot glue the same way to the shrink tubing of the BME sensor and place it right next to the slot in the lower part of the gnome body top, with the sensor facing downwards.

## Flashing the firmware

Make sure the power is disconnected from the Datenzwerg's mainboard. Unplug the D1 mini from the mainboard and connect it to your computer via USB.

Install Python 3.11. Check out the [GitHub repository](https://github.com/romses/Datenzwerg) and therein run 

1. `python -m venv venv`
2. `source venv/bin/activate`
3. `pip install -r requirements.txt`

This will install all dependencies needed to build the firmware and the documentation into a virtual environment and activate it.

Then, navigate to the `firmware` directory. Copy `secrets-template.yaml` to `secrets.yaml` and fill in your WiFi, MQTT and InfluxDB2 credentials and also set an OTA password if wanted. Make desired adjustments of packages to be compiled in in `datenzwerg.yaml`. Then run

```
esphome -s name <gnome> -s eco2_baseline <eco2 baseline> -s tvoc_baseline <tvoc baseline> run datenzwerg.yaml
```
to compile and flash the firmware for your Datenzwerg named `<gnome>` with the eCO2 baseline `<eco2 baseline>` and the TVOC baseline value `<tvoc baseline>`.

E.g. if you want to flash the firmware for the gnome named `zwerg` with eCO2 baseline `0x7F10` and TVOC baseline `0x88B4`, run `esphome -s name zwerg -s eco2_baseline 0x7F10 -s tvoc_baseline 0x88B4 run datenzwerg.yaml`. If you don't yet have baseline values, you can leave them out: `esphome -s name zwerg run datenzwerg.yaml`.

!!! warning

    The checked in version of the firmware is currently optimized for v1.1 with MicroUSB powered deployment, as the TVOC sensor added in v1.1 requires constant power for sensible readings.

    If you want to use the firmware with a battery powered Datenzwerg, you will need to adjust the firmware config to enable deep sleep by removing the comment in front of the `deepsleep` package in `firmware/datenzwerg.yaml` and commenting out the `tvoc` and `uptime` packages:

    ```yaml
    packages:
      base: !include packages/base.yaml # base v1.0 sensor package
      #tvoc: !include packages/tvoc.yaml # TVOC sensor added in v1.1, incompatible to battery power
      deepsleep: !include packages/deepsleep.yaml  # enable this on battery power
      #uptime: !include packages/uptime.yaml  # disable this on battery power
    
      # these should not be enabled in production
      #ota: !include packages/ota.yaml
      #webserver: !include packages/webserver.yaml

    ```

    If you do not compile with the TVOC package included, you can leave out the `eco2_baseline` and `tvoc_baseline` parameters during compilation.

Plug the D1 mini back into the mainboard and reconnect the power. It should connect to your WiFi and start sending data to the configured InfluxDB.

[^1]: We sourced our LiPo batteries from some old USB power banks we happened to have.
[^2]: We did this by holding the disc with pliers. For sanding, we pressed it against a disc sander on the lowest setting, with the right grit. For polishing, we rubbed it manually again and again on a microfibre cloth with the polishing compound applied, lying on top of a flat hard surface. Don't forget to do both sides!

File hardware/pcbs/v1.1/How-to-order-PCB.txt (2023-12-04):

How to Order PCB

Please refer to:
https://docs.easyeda.com/en/PCB/Order-PCB

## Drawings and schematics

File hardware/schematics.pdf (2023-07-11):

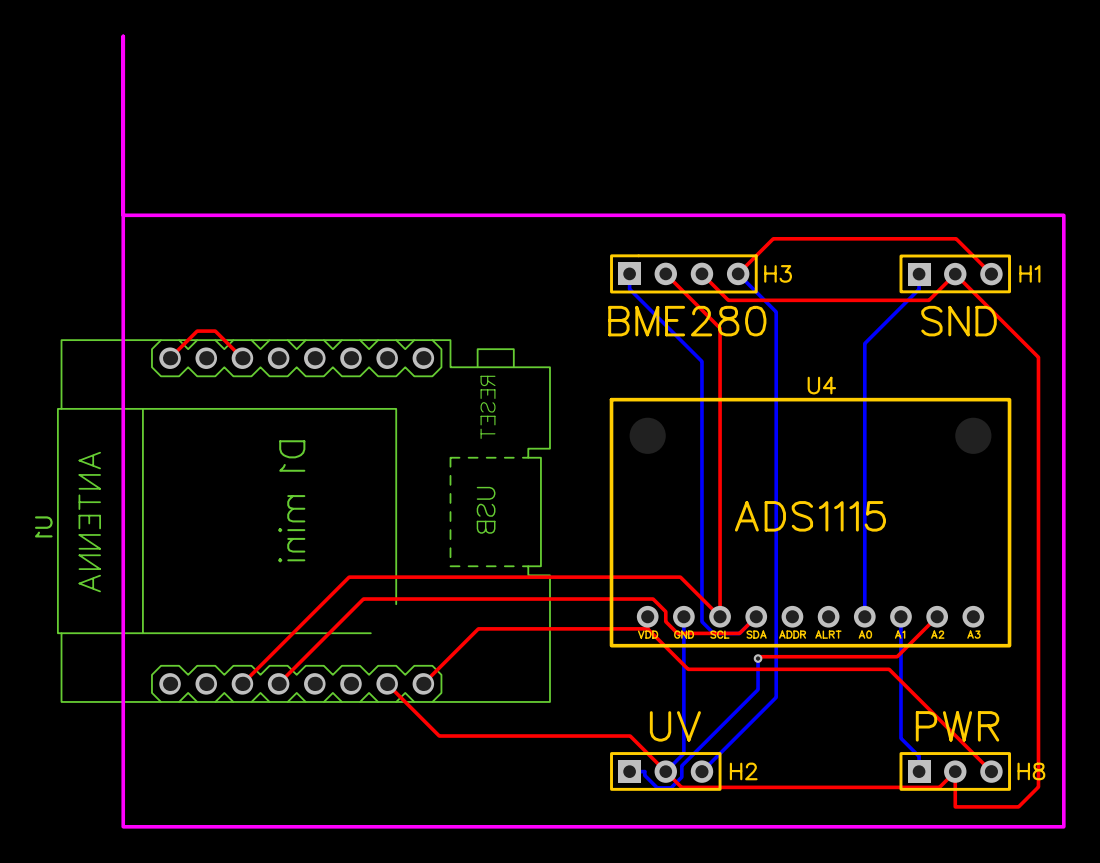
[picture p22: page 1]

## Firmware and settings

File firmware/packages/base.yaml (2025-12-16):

substitutions:
  name: gnome
  update_interval: 5s

esphome:
  name: "datenzwerg-${name}"

esp8266:
  board: d1_mini
  framework:
    version: recommended

http_request:
  verify_ssl: false

external_components:
  - source:
      type: local
      path: components
    components: [ git_ref, influxdb2 ]

logger:

wifi:
  networks:
    - ssid: 39C3
      eap:
        username: outboundonly
        password: outboundonly
    - ssid: 39C3-open

    # fallback from secrets
    - ssid: !secret wifi_ssid
      password: !secret wifi_psk

  on_connect:
    - delay: 1s
    - lambda: |-
        id(esphome_version_sensor).publish_state(id(esphome_version_sensor).state);
        id(git_ref_sensor).publish_state(id(git_ref_sensor).state);

mdns:
  disabled: true

i2c:
  scl: D1
  sda: D2
  id: bus_a

switch:
  - platform: restart
    name: "Restart"

ads1115:
  - address: 0x48

sensor:
  - platform: wifi_signal
    name: "WiFi Signal"
    update_interval: ${update_interval}

  - platform: bme280_i2c
    temperature:
      name: "Temperature"
      oversampling: 16x
      id: bme280_temperature
    pressure:
      name: "Pressure"
      id: bme280_pressure
    humidity:
      name: "Humidity"
      id: bme280_humidity
    address: 0x76
    update_interval: ${update_interval}

  - platform: ads1115
    gain: 6.144
    multiplexer: 'A0_GND'
    name: 'UV Voltage'
    id: uv_voltage
    update_interval: ${update_interval}

  - platform: ads1115
    gain: 6.144
    multiplexer: 'A1_GND'
    name: 'Battery Voltage'
    id: battery_voltage
    update_interval: ${update_interval}

  - platform: template
    name: "UV Index"
    update_interval: ${update_interval}
    lambda: |-
      float value = id(uv_voltage).state;
      ESP_LOGD("uv_index", "The UV voltage is: %f", value);
      if (value >= 1.170) {
        return 11.0;
      } else if (value >= 1.079) {
        return 10.0;
      } else if (value >= 0.976) {
        return 9.0;
      } else if (value >= 0.881) {
        return 8.0;
      } else if (value >= 0.795) {
        return 7.0;
      } else if (value >= 0.696) {
        return 6.0;
      } else if (value >= 0.606) {
        return 5.0;
      } else if (value >= 0.503) {
        return 4.0;
      } else if (value >= 0.408) {
        return 3.0;
      } else if (value >= 0.318) {
        return 2.0;
      } else if (value >= 0.227) {
        return 1.0;
      } else {
        return 0.0;
      }

  - platform: template
    name: "Altitude"
    lambda: |-
      const float STANDARD_SEA_LEVEL_PRESSURE = 1013.25; //in hPa, see note
      return ((id(bme280_temperature).state + 273.15) / 0.0065) *
        (powf((STANDARD_SEA_LEVEL_PRESSURE / id(bme280_pressure).state), 0.190234) - 1); // in meter
    update_interval: ${update_interval}
    icon: 'mdi:signal'
    unit_of_measurement: 'm'

  - platform: absolute_humidity
    name: "Absolute Humidity"
    temperature: bme280_temperature
    humidity: bme280_humidity

  - platform: template
    name: "Dew Point"
    lambda: |-
      float T = id(bme280_temperature).state;
      float R = id(bme280_humidity).state;
      return (
        243.5 * (
          log(R / 100) 
          + (
            (17.67 * T) / (243.5 +T )
          )
        ) / (
          17.67 - log(R/100) - (
            (17.67 * T) / (243.5 + T)
          )
        )
      );
    unit_of_measurement: °C
    icon: 'mdi:thermometer-alert'
    update_interval: ${update_interval}

  - platform: template
    name: "Heat index"
    lambda: |-
      float T = id(bme280_temperature).state;
      float R = id(bme280_humidity).state;
      float Tsq = pow(T, 2.0);
      float Rsq = pow(R, 2.0);
      return (-8.78469475556 + 1.61139411 * T + 2.33854883889 * R - 0.14611605 * T * R 
        - 0.012308094 * Tsq - 0.0164248277778 * Rsq 
        + 2.211732e-3 * Tsq * R + 7.2546e-4 * T * Rsq 
        - 3.582e-6 * Tsq * Rsq);
    unit_of_measurement: °C
    update_interval: ${update_interval}

  - platform: adc
    pin: A0
    name: "Sound Voltage"
    id: sound_voltage
    update_interval: ${update_interval}
    filters:
    - multiply: 3.3

text_sensor:
  - platform: version
    hide_timestamp: true
    name: "ESPHome Version"
    id: esphome_version_sensor

  - platform: wifi_info
    ip_address:
      name: "IP"
      icon: mdi:wifi
    ssid:
      name: "SSID"
      icon: mdi:wifi-strength-2

  - platform: git_ref
    name: "Git Ref"
    long: true
    all: true
    dirty: "-dirty"
    id: git_ref_sensor

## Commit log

2023-07-11 â✨ Project datagnome was born
    [datenzwerg_40p_1.2mm_bottom.stl, datenzwerg_40p_1.2mm_bottom_filled.stl, datenzwerg_40p_1.2mm_top.stl]
2023-07-11 👷 Add doc build workflow
2023-07-11 📝 Use default site folder for docs build
    Otherwise the page build will fail
2023-07-11 ✨ Traefik configuration to redirect requests to github-pages
2023-07-12 ✨ Added pages for sensor dashboards
2023-07-12 📝 Added sensor iframes to web site
2023-07-12 📝 Added sensor pages ✨ Added virtual sensors for absolute humidity and dew point
2023-07-12 ✨ Add altitude calculation to sensor values
2023-07-12 Removed incompatible update_interval for sensor Absolutee Humidity
2023-07-12 📝 Addeded metadata tab
2023-07-13 🐛 Fix update interval for dew point
2023-07-13 💄 Make iframes fill the width in 16:9
2023-07-13 💄 Use config & templates for grafana embeds
2023-07-13 🐛 Fix swapped panels
2023-07-13 🔧 Make site_url and grafana base env configurable
    Two new environment vars supported:
    - SITE_URL: site url to use, defaults to http://127.0.0.1:8000
    - GRAFANA_BASE: grafana base to use, defaults to http://grafana.datagnome.de/grafana/d-solo/f17a6449-84ed-4733-b982-21c0d480c42a/
2023-07-13 🐛 ACTUALLY make site_url and grafana configurable
2023-07-13 📝 More work on build instructions
    English only for now, to be translated
2023-07-13 🐛 Hopefully fix i18n on github pages
2023-07-13 Datagnome fritzing schematic
2023-07-13 🐛Fixed a link in the english documentation
2023-07-13 🐛fixed a link in the sensor page
2023-07-14 Removed uptime sensor -> Uptime with deep is somehow pointless
2023-07-14 🚧 Sound pressure sensor, currently not compiling
2023-07-14 🙈 Add pycache to firmware gitignore
2023-07-16 🍱 Added Images and schematics
    [BME280.fzz, Datenzwerg.fzz, Power-module.fzz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]
2023-07-16 📝 Updated the english build documentation
2023-07-16 Added untested gerber files for PCB manufacturing
2023-07-16 Fixed wrong schematic
    [Datenzwerg.fzz]
2023-07-18 ♻️ Remove screw hole from gnome hat
    We'll use hot glue instead for securing the UV
    sensor.
    [datenzwerg_40p_1.2mm_top.stl]
2023-07-18 🙈 Add blender backup to gitignore
2023-07-18 🗑️ Get rid of unused model files
    [datenzwerg_40p_1.2mm_bottom.stl, datenzwerg_40p_1.2mm_bottom_filled.stl]
2023-07-18 📝 Work on the docs
    - fixed some typos
    - rewrote some bits and pieces
    - updated assembly of gnome body
2023-07-19 📝 Updated the build instructions
2023-07-19 🐛 ficed document formatting
2023-07-19 🐛 fixed prices
2023-07-22 Switch page to datagnome.de
2023-07-22 🔒️ Updated the docker stack
2023-07-22 🔒️ removed traefik admin interface and dummy credentials
2023-07-23 🐛 Fixed grafana links
2023-07-23 🐛 Fixed grafana links (2/x)
2023-07-23 🐛 Fixed grafana links (3/x)
2023-07-24 ✨ First promising sound sensor implementation (#1)
    Sound voltage is now captured from the ESP's own ADC instead
    of using the ADS1115, which proved to not be up to the task.
    Peak to peak envelope is calculated over a sample duration of
    1s, this is moved back to a voltage range of 0-3.3V, then an RMS
    is approximated by multiplying with 0.7071, and finally a sound
    pressure value is calculated based on
    https://electronics.stackexchange.com/a/219721
    The resulting dBSPL values still seem too high, I have the suspicion
    the microphone on our MAX4466 boards might not have a
    sensitivity of -44dB like the one on the Adafruit boards, but I was
    not able to source that piece of inf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
2023-07-24 📝 Some more doc work
    - picture of rain cover stages
    - typos fixed in docs and mentioned shrink tubing
    - fixed grafana embeds
2023-07-25 🚸 Added http to https redirect
2023-07-26 Corrected the schematics
    Snd now connrcts to the internal adc of the esp, and UV was incorrectply connected to pds1115:A2
    [Datenzwerg.fzz]
2023-07-31 💄 Improve mastowall embed
2023-07-31 💄 Make logo scale responsively
2023-08-04 Corrected cable coloring
    [BME280.fzz, Datenzwerg.fzz]
2023-08-04 corrected schematic again
    [Datenzwerg.fzz]
2023-08-07 Add git ref text sensor to firmware
2023-08-08 Manually push states of text sensors
    Otherwise they will only ever try to push
    on boot, when we don't yet have a network
    connection.
2023-08-14 Switch CCCamp network
2023-08-15 Add FAQ re temperature readings
2023-08-22 added CSV Export
    [absolute_humidity.csv, altitude.csv, battery_voltage.csv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]
2023-08-29 Updated Gerber Files to represent the latest hardware changes
2023-12-02 Added a new PCB with TVOC port
2023-12-02 Gerber files for datagnome with TVOC port
2023-12-04 Some clean up in the directory structure
    Also mentioned that work on the 37c3 version has started.
    [BME280.fzz, Datenzwerg.fzz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]
2023-12-05 Add POE version of gnome bottom
    [datenzwerg_40p_1.2mm_bottom_poe.stl]
2023-12-10 Current firmware updates
2023-12-11 Remove use of BME compensation for SGP30
    Seems to finally make that sensor put out somewhat normal data.
2023-12-11 Add additional panels to current data overview
2023-12-11 Link to sensors page
2023-12-21 Update base.yaml
    Fixed indentation typo
    [base.yaml]
2023-12-22 Prepare package for SCD41 sensor
2023-12-28 CO2 sensor added to Hefty and Dashboard was updated
2023-12-28 Joint eCO2/CO2 Panel
2024-01-04 Update how_to_build.de.md
    Link where some components can be ordered from a German dealer (Reichelt elektronik)
2024-01-04 Update how_to_build.de.md
    Adds two more components that can be purchased from reichelt elektronik.
2024-05-30 Remove UV Index from sensors page
2024-06-04 L-Boxx models
    [l-boxx-136-inlay.FCStd]
2024-12-16 add plate & l-boxx labels
2025-08-03 add ground plate design files & stl
    [ground-plate-bottom.FCStd, ground-plate-bottom.stl]
